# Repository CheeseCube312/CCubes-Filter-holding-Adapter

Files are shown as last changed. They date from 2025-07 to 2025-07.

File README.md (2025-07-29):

**This 3D-printable vintage lens adapter allows users to place optical filters behind the camera lens**

It has been designed because large specialty filters are expensive and sometimes don't exist while gel filters are fragile and easy to mount. It supports glass-filters with 1-3mm thickness and a 20-39mm diameter aswell as thin 1.5x1.5 inch filter squares.

Both CAD and 3D-printing files are provided in .step and .3mf format respectively. 

Supported lens mounts:
- M42
- Minolta MD
- Konica AR (modified design, not cross-compatible, thus seperate .zip file)
- more will be added

Supported camera mounts:
- Sony E/FE
- Nikon Z [untested]
- Canon RF [untested]

Please read parts list and assembly instructions below.

**Required Materials:**
- 1x Generic "super slim" M42 to [camera mount] adapter (see linked photo)
- 6x M2.5 heat insert
- 4x Screws: M2.5 x 16mm Torx Flathead
- 2x Screws: M2.5 x 6mm Torx Flathead
- Glue (I used Cyanoacrylate aka. "Superglue" for PLA/PETG)

**Required tools:** 
- 3D printer
- soldering iron (for heat inserts)
- fine screwdriver
- optional: lighter (to clean up the print)

**Building the adapter**:
1. order the parts you need
2. 3D print the 3 parts of the adapter body required for your camera mount (top, middle, bottom)
3.  place top piece with lens-mount facing down
4. melt M2.5 heat inserts into the bottom holes of the top piece (4x total)
5. apply glue to the middle piece
6. line up holes in middle piece with the top and place down
7. line up holes in the bottom piece with the middle and place down
8. use M2.5 x 16mm screws to firmly screw all the parts together (4x total)
9. let glue dry

**Notes Adapter:**
- **flip the bottom part 180° before printing so it doesn't have overhangs**
- do a dry fit before applying glue to check if everything lines up 
- screw M2.5x16 screws into the heat inserts before glue application to clear stuck filament from the threads
- spread glue with toothpick for even coverage and less squeeze-out

**Building the filter holder:**
1. Select the right filter holder for you
2. 3D-print holder and holding-plates
3. melt M2.5 heat inserts into the filter holder (2x total)
4. place filters and hold down with M2.5 x 6mm screw (2x total)

**Notes Filter Holder:**
- the naming convention is "Holder - [diameter]x[thickness] filter.3mf, refering to the glass filters size
- all filter holders are made for 1.5x1.5 inch filter squares. Only difference is the size of glass filters they can take. If you have no glass filters just print 36x1 filter holder for good mix of rigidity and vignetting-resistance
- it's explicitly designed to take both filter types at the same time so you can create filter stacks
- I encourage making more than one filter holder since it's far easier to change them out than to change the individual filters

**Printing Tips:**
- I just used PLA and PETG. Both worked mostly fine. Sturdier filaments should offer more peace of mind but are harder to print
- one PLA prototype made on a printer with underextrusion issues broke at the bottom plate interface between the screw-thread and flat surface. It has been reinforced significantly but beware, it's a stress point
- all final pre-release prints were done in "0.12mm High Quality" preset on a Bambu Labs A1 Mini

You are free to use, re-upload, modify and make commercial use of this project and any derivative works you create based on in accordance with the simple and permissive licensing terms granted by CC BY license. Feedback is very welcome. 

The specific type of adapter plate this is all designed for:
https://i.ebayimg.com/images/g/y7oAAOSwjWlhC49V/s-l1600.jpg

Edit 23.07.2025: Fixed filter holder issue where sharp corners get stuck. Now rounded.

Edit 24.07.2025: Fixed glass filter diameter, added tollerance for printing

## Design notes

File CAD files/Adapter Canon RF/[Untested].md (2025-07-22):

This adapter-design has not been tested by CheeseCube on an actual camera. There's a chance of focus-issues like lack of infinity focus. 

Feedback is very welcome.

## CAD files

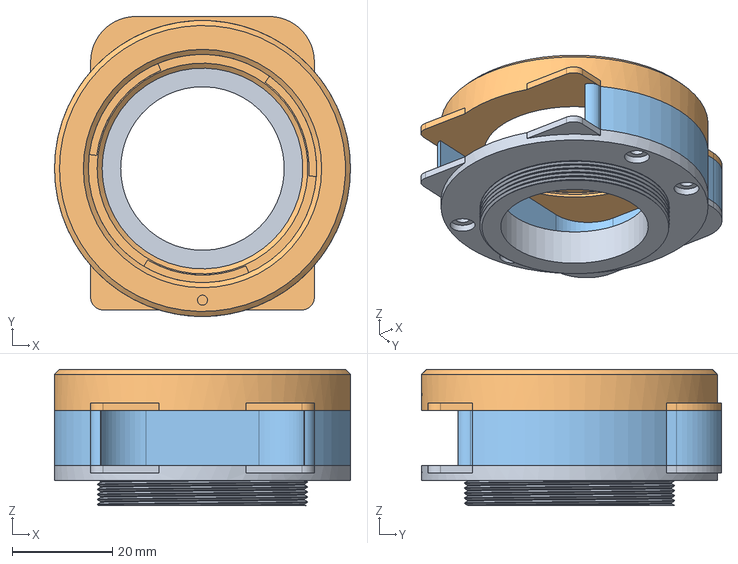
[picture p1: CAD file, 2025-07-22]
CAD files/Adapter Canon RF/Adapter MD - Canon RF.step
59.0 x 59.8 x 27.2 mm

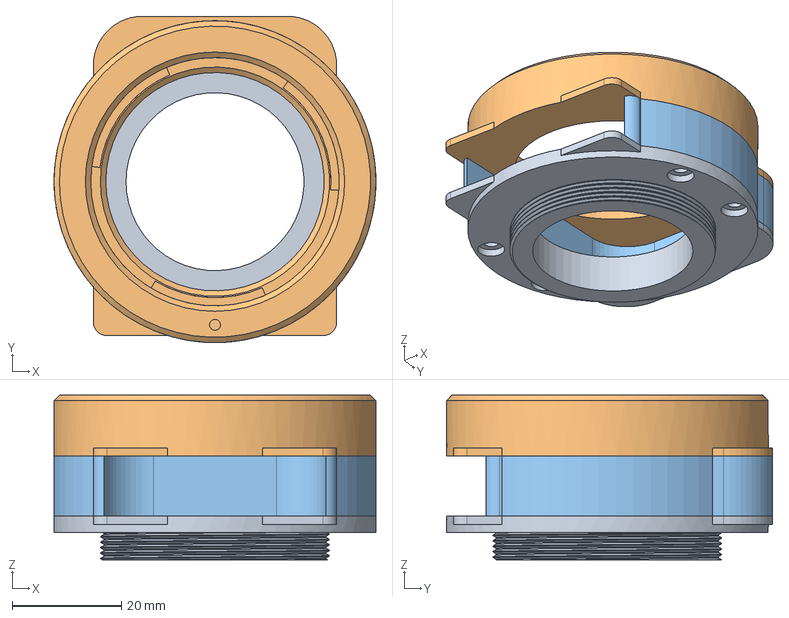
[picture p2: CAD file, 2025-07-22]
CAD files/Adapter Nikon Z/Adapter MD - Nikon Z.step
59.0 x 59.8 x 30.2 mm

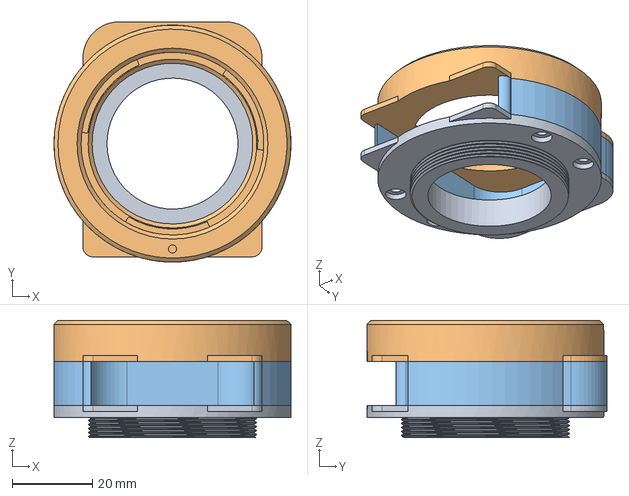
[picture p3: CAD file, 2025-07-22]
CAD files/Adapter Sony E/Adapter MD - NEX.step
59.0 x 59.8 x 29.2 mm

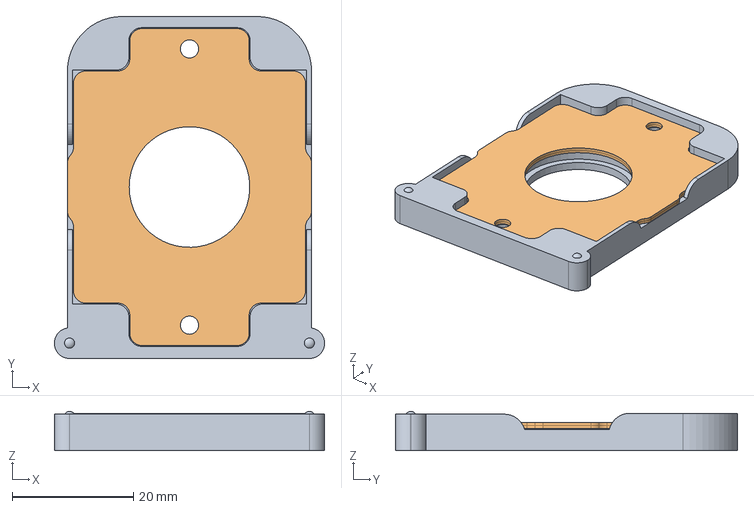
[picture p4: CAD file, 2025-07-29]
Konica AR/CAD/Fitler Holder/Holder - 22x2mm filter.step
44.6 x 56.5 x 6.45 mm

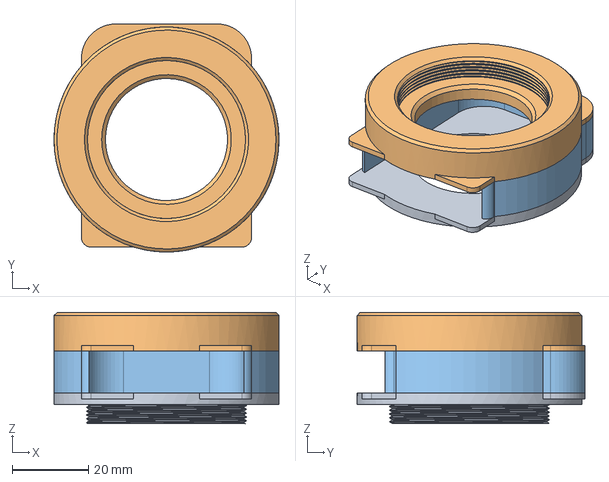
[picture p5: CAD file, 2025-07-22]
CAD files/Adapter Canon RF/Adapter M42 - Canon RF.step
59.0 x 59.8 x 29.2 mm

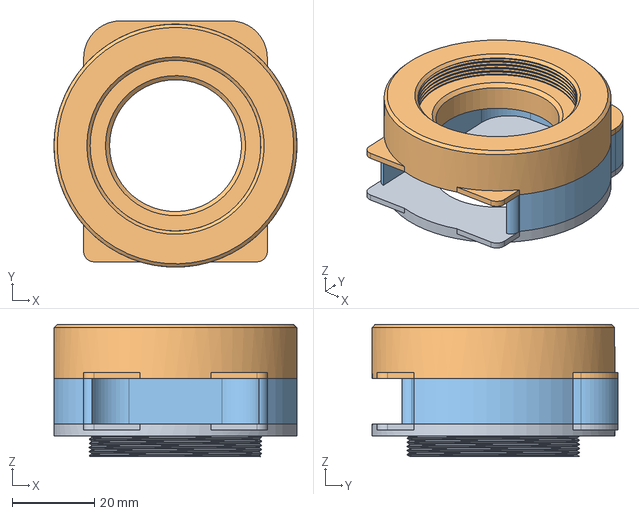
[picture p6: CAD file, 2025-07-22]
CAD files/Adapter Nikon Z/Adapter M42 - Nikon Z.step
59.0 x 59.8 x 32.2 mm

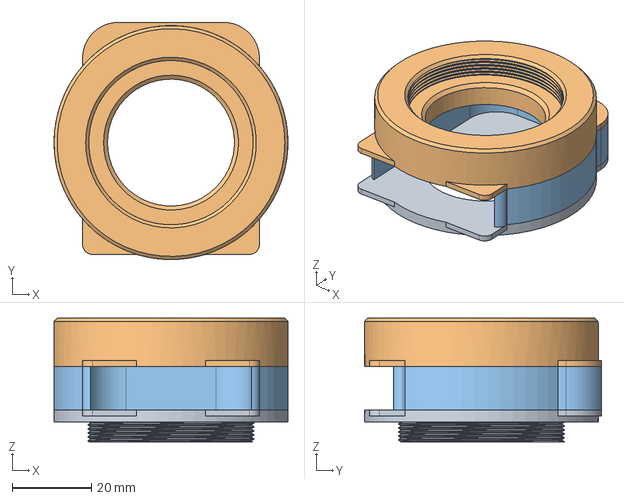
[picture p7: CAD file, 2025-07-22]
CAD files/Adapter Sony E/Adapter M42 - NEX.step
59.0 x 59.8 x 31.2 mm

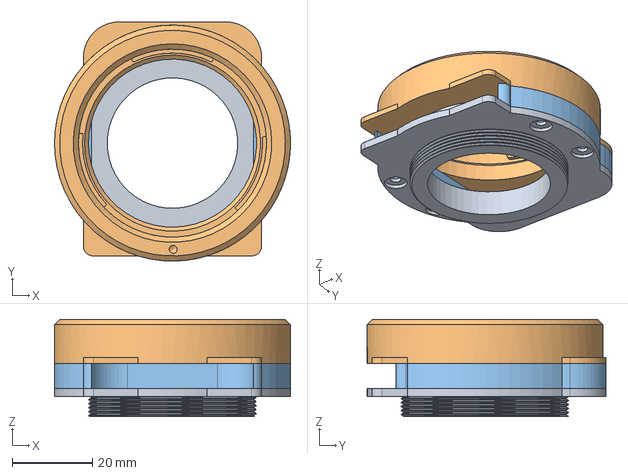
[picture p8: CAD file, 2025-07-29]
Konica AR/CAD/Filter-Adapter V6 KAR - Canon RF.step
59.0 x 59.8 x 24.3 mm

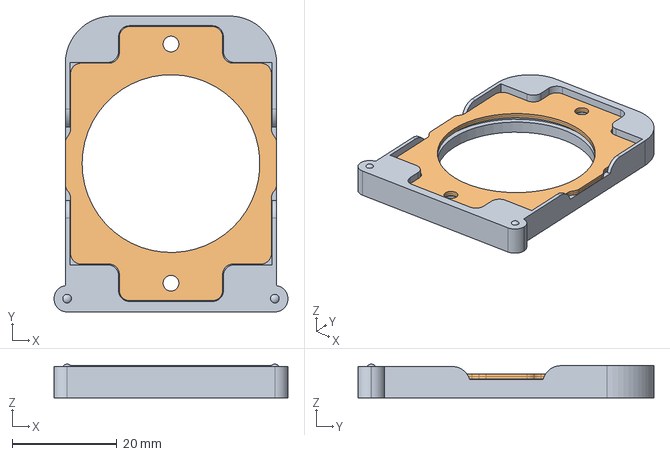
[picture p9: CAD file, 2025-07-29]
Konica AR/CAD/Fitler Holder/Holder - 36x1mm filter.step
44.6 x 56.5 x 6.45 mm

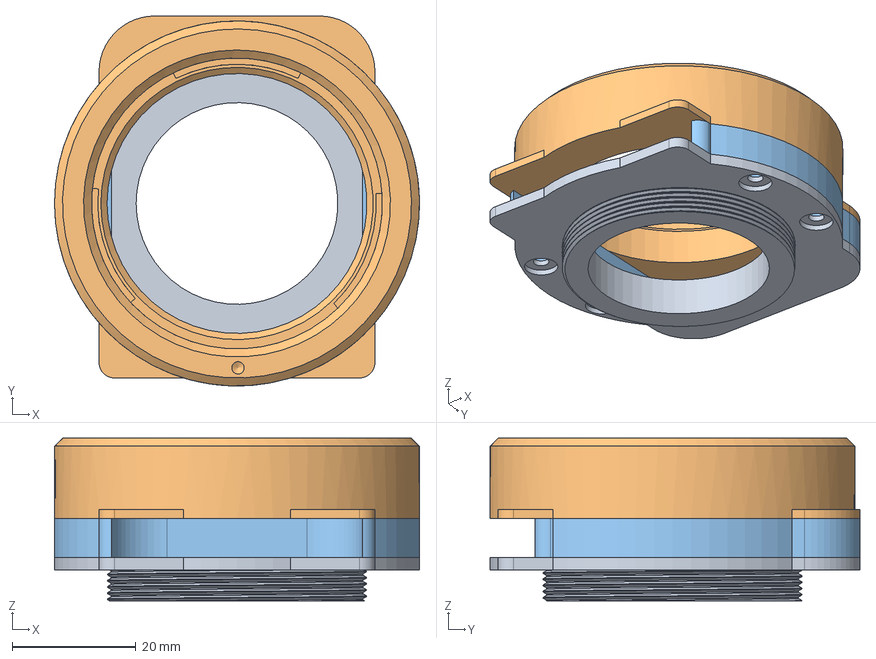
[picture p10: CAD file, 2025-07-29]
Konica AR/CAD/Filter-Adapter V6 KAR - Sony E.step
59.0 x 59.8 x 26.3 mm

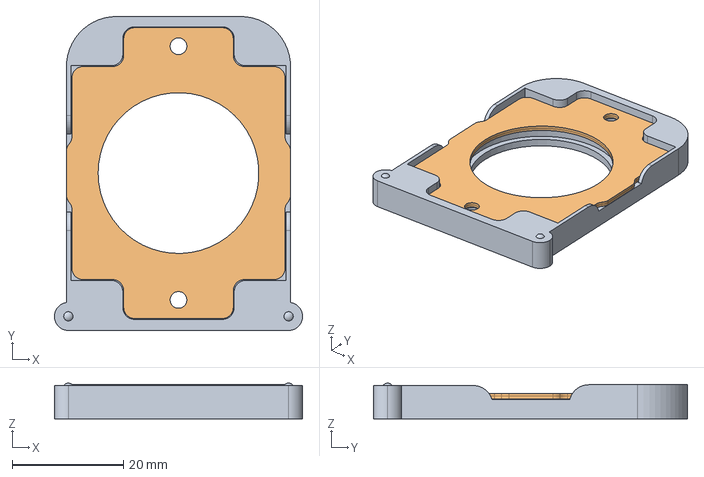
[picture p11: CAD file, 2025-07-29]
Konica AR/CAD/Fitler Holder/Holder - 31x2mm filter.step
44.6 x 56.5 x 6.45 mm

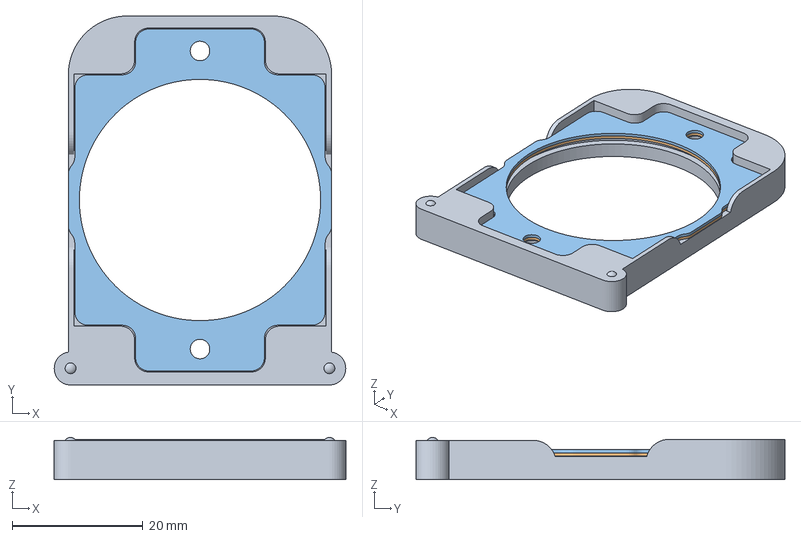
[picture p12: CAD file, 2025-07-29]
Konica AR/Print/Filter Holder/Holder - 39x1mm filter.3mf
44.6 x 56.5 x 6.45 mm
Filter Holder Body
Holder Plate Glass
Holder Plate Normal

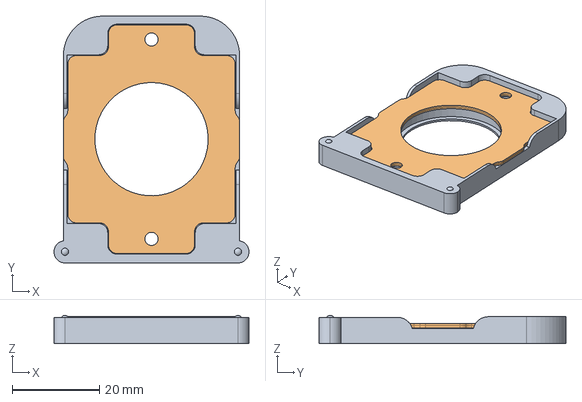
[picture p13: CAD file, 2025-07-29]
Konica AR/CAD/Fitler Holder/Holder - 28x3mm filter.step
44.6 x 56.5 x 6.45 mm

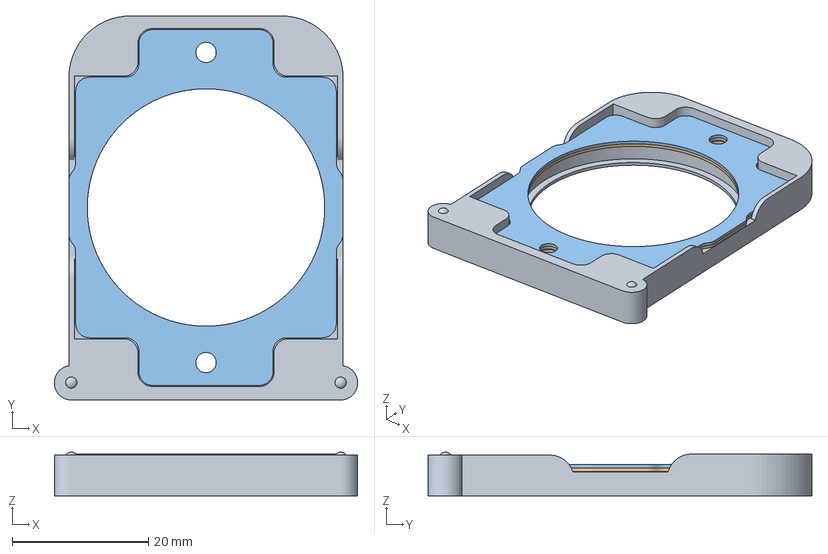
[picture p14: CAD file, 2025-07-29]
Konica AR/Print/Filter Holder/Holder - 37x3mm filter.3mf
44.6 x 56.5 x 6.45 mm
Filter Holder Body
Holder Plate Glass
Holder Plate Normal

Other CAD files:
Konica AR/CAD/Filter-Adapter V6 KAR - Nikon Z.step
Konica AR/Print/Filter Holder/Holder - 22x3mm filter.3mf
Konica AR/Print/Filter Holder/Holder - 21x3mm filter.3mf
Konica AR/CAD/Fitler Holder/Holder - 24x2mm filter.step
CAD files/Standart Filter Carrier/Holder - 20x1mm filter.step
CAD files/Standart Filter Carrier/Holder - 20x2mm filter.step
CAD files/Standart Filter Carrier/Holder - 20x3mm filter.step
CAD files/Standart Filter Carrier/Holder - 21x1mm filter.step
CAD files/Standart Filter Carrier/Holder - 21x2mm filter.step
CAD files/Standart Filter Carrier/Holder - 21x3mm filter.step
CAD files/Standart Filter Carrier/Holder - 22x1mm filter.step
CAD files/Standart Filter Carrier/Holder - 22x2mm filter.step
CAD files/Standart Filter Carrier/Holder - 22x3mm filter.step
CAD files/Standart Filter Carrier/Holder - 23x1mm filter.step
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

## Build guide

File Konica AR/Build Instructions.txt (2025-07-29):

**Why this adapter differs from the others?**

1. Konica AR has a very short flange focal distance for a vintage SLR mount
2. The aperture measuring pin protrude quite far from the back of the lens (~11mm)

So, the adapter had to be modified so the fitler carrier clears the lens. The filter carrier still allows the use of up to 3mm thick 
glass filters but doesn't have a retaining ring on the holding plate. It's significantly flatter so not cross-compatible.

** PARTS LIST**

- 6x M2.5 heat inserts (less than 3.5mm long)
- 4x M2.5x14mm screw (flat top)
- 2x M2.5x5mm screw (flat top)
- glue (CA glue worked well on PETG/PLA)

** BUILD INSTRUCTIONS **

Adapter:
1. Download and print the model
2. melt heat-inserts into top piece holes (4x)
3. add glue to mounting surface
4. line up middle piece, place down
5. add glue to next mounting surface
6. line up bottom piece, place down
7. stick M2.5x14mm through holes, screw everything together
8. clean up squeeze-out if desired

Filter carrier:
1. Download
2. Select carrier meant for your glass filter. If you don't have one just choose a big carrier (36mm+ for full-frame)
3. Print
4. melt M2.5 heat-inserts into main carrier plate
5. screw M2.5 screw into heat-inserts to clean out any molten plastic

Additional Tipps:
- make sure your print has good layer adhesion!
- print the top and bottom plates extra sturdy. They're particularly load bearing
- test-fit parts before applying glue
- let the glue cure properly! Can take more than a day with CA glue
- be careful with heavy lenses

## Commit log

2025-07-22 First Commit
    includes all the current adapter types and filter holders.
    [Adapter M42 - Canon RF.3mf, Adapter M42 - Canon RF.step, Adapter M42 - NEX.3mf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]
2025-07-23 Updated filter holder
    - fixes issue where it gets stuck
    [Holder - 20x1mm filter.3mf, Holder - 20x1mm filter.step, Holder - 20x2mm filter.3mf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]
2025-07-24 Updated Filter Holder
    [Holder - 20x1mm filter.3mf, Holder - 20x1mm filter.step, Holder - 20x2mm filter.3mf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]
2025-07-29 Konica AR added
    Konica AR is distinctive remodel.
    [Filter-Adapter V6 KAR - Canon RF.3mf, Filter-Adapter V6 KAR - Canon RF.step, Filter-Adapter V6 KAR - Nikon Z.3mf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]
